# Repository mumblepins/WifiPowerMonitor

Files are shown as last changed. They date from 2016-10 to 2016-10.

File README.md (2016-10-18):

# Particle power monitor

Uses the [Particle](http://particle.io) Photon by default, but probably would work with a Core or one of the other Particle type devices.

Interfaces with a ST STPM34 ADC power-monitoring front-end and is designed for 2 CTs and 2 voltage inputs.  Resistors are sized in general for a 100A → 50mA current transformer, and 120V (US) voltage source.  Unlike the [OpenEnergyMonitor](https://openenergymonitor.org/emon/), we're using a seperate 24-bit ADC, and no voltage transformer. 

###License
#### Hardware
<br />This work is licensed under a <a rel="license" href="http://creativecommons.org/licenses/by-sa/4.0/">Creative Commons Attribution-ShareAlike 4.0 International License</a>.

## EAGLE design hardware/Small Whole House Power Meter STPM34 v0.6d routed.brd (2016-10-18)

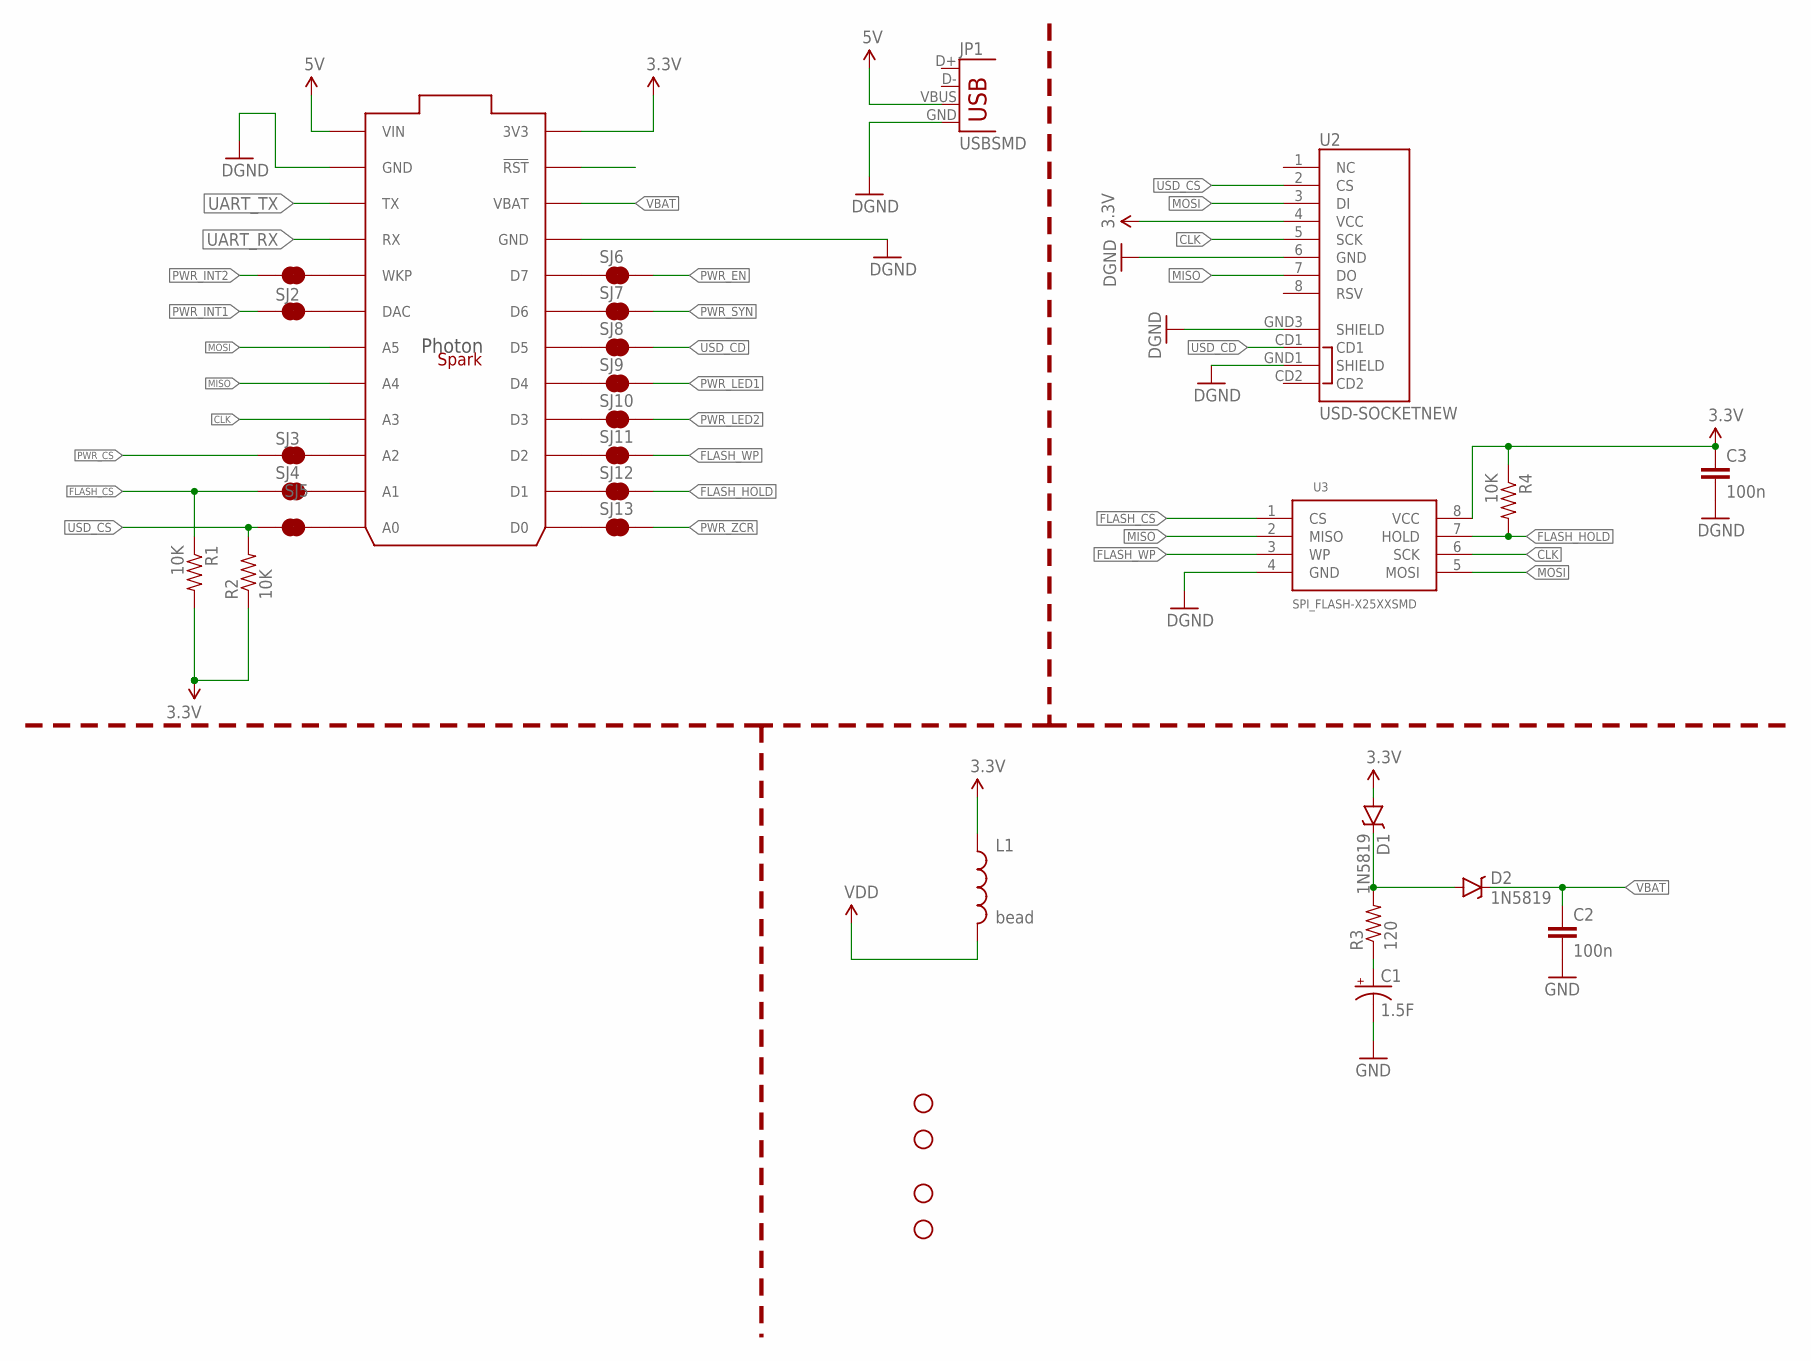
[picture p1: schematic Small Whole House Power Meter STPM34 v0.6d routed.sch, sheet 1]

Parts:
C1: 1.5F; 1.5SUPERCAPHORIZ
C2, C3: 100n; 0603-CAP
D1, D2: 1N5819; SOD-123
JP1: USBSMD; USB-MINIB
L1: bead; 0603
M1: SPARK_LOGO..; SPARK_LOGO
R1, R2, R4: 10K; 0603-RES
R3: 120; 0603-RES
SJ1, SJ2, SJ3, SJ4, SJ5, SJ6, SJ7, SJ8, SJ9, SJ10, SJ11, SJ12, SJ13: JUMPER-PAD-2-NC_BY_TRACE; PAD-JUMPER-2-NC_BY_TRACE_YES_SILK
STANDOFF1, STANDOFF2, STANDOFF3, STANDOFF4: STAND-OFF
U1: PHOTON_SMD_W_PINS
U2: USD-SOCKETNEW; MICRO-SD-SOCKET-PP
U3: SPI_FLASH-X25XXSMD; SO08N/W

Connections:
3.3V: C3.1, D1.A, L1.1, R1.2, R2.1, R4.1, U1.1_24 (3V3), U1.24 (3V3), U1.24* (3V3), U1.24_ (3V3), U2.4 (VCC), U3.8 (VCC)
5V: JP1.VBUS, U1.1 (VIN), U1.1* (VIN), U1.1_ (VIN), U1.1_1 (VIN)
CLK: U1.1_9 (A3), U1.9 (A3), U1.9* (A3), U1.9_ (A3), U2.5 (SCK), U3.6 (SCK); also elsewhere on the board
FLASH_CS: R1.1, SJ4.1, U3.1 (CS)
FLASH_HOLD: R4.2, SJ12.2, U3.7 (HOLD)
FLASH_WP: SJ11.2, U3.3 (WP)
GND: C1.-, C2.2, C3.2, JP1.GND, U1.1_2 (GND), U1.1_21 (GND), U1.2 (GND), U1.2* (GND), U1.2_ (GND), U1.21 (GND), U1.21* (GND), U1.21_ (GND), U2.6 (GND), U2.GND1 (SHIELD), U2.GND3 (SHIELD), U3.4 (GND); also elsewhere on the board
MISO: U1.1_8 (A4), U1.8 (A4), U1.8* (A4), U1.8_ (A4), U2.7 (DO), U3.2 (MISO); also elsewhere on the board
MOSI: U1.1_7 (A5), U1.7 (A5), U1.7* (A5), U1.7_ (A5), U2.3 (DI), U3.5 (MOSI); also elsewhere on the board
unnamed: SJ13.1, U1.1_13 (D0), U1.13 (D0), U1.13* (D0), U1.13_ (D0)
unnamed: U1.1_23 (!RST), U1.23 (!RST), U1.23* (!RST), U1.23_ (!RST)
unnamed: C1.+, R3.1
unnamed: SJ11.1, U1.1_15 (D2), U1.15 (D2), U1.15* (D2), U1.15_ (D2)
unnamed: SJ4.2, U1.1_11 (A1), U1.11 (A1), U1.11* (A1), U1.11_ (A1)
unnamed: SJ3.2, U1.1_10 (A2), U1.10 (A2), U1.10* (A2), U1.10_ (A2)
unnamed: SJ2.2, U1.1_6 (DAC), U1.6 (DAC), U1.6* (DAC), U1.6_ (DAC)
unnamed: SJ1.2, U1.1_5 (WKP), U1.5 (WKP), U1.5* (WKP), U1.5_ (WKP)
unnamed: SJ6.1, U1.1_20 (D7), U1.20 (D7), U1.20* (D7), U1.20_ (D7)
unnamed: SJ7.1, U1.1_19 (D6), U1.19 (D6), U1.19* (D6), U1.19_ (D6)
unnamed: SJ8.1, U1.1_18 (D5), U1.18 (D5), U1.18* (D5), U1.18_ (D5)
unnamed: SJ9.1, U1.1_17 (D4), U1.17 (D4), U1.17* (D4), U1.17_ (D4)
unnamed: SJ12.1, U1.1_14 (D1), U1.14 (D1), U1.14* (D1), U1.14_ (D1)
unnamed: SJ10.1, U1.1_16 (D3), U1.16 (D3), U1.16* (D3), U1.16_ (D3)
unnamed: D1.C, D2.A, R3.2
unnamed: SJ5.2, U1.1_12 (A0), U1.12 (A0), U1.12* (A0), U1.12_ (A0)
PWR_CS: SJ3.1; also elsewhere on the board
PWR_EN: SJ6.2; also elsewhere on the board
PWR_INT1: SJ2.1; also elsewhere on the board
PWR_INT2: SJ1.1; also elsewhere on the board
PWR_LED1: SJ9.2; also elsewhere on the board
PWR_LED2: SJ10.2; also elsewhere on the board
PWR_SYN: SJ7.2; also elsewhere on the board
PWR_ZCR: SJ13.2; also elsewhere on the board
UART_RX: U1.1_4 (RX), U1.4 (RX), U1.4* (RX), U1.4_ (RX)
UART_TX: U1.1_3 (TX), U1.3 (TX), U1.3* (TX), U1.3_ (TX)
USD_CD: SJ8.2, U2.CD1
USD_CS: R2.2, SJ5.1, U2.2 (CS)
VBAT: C2.1, D2.C, U1.1_22 (VBAT), U1.22 (VBAT), U1.22* (VBAT), U1.22_ (VBAT)
VDD: L1.2; also elsewhere on the board

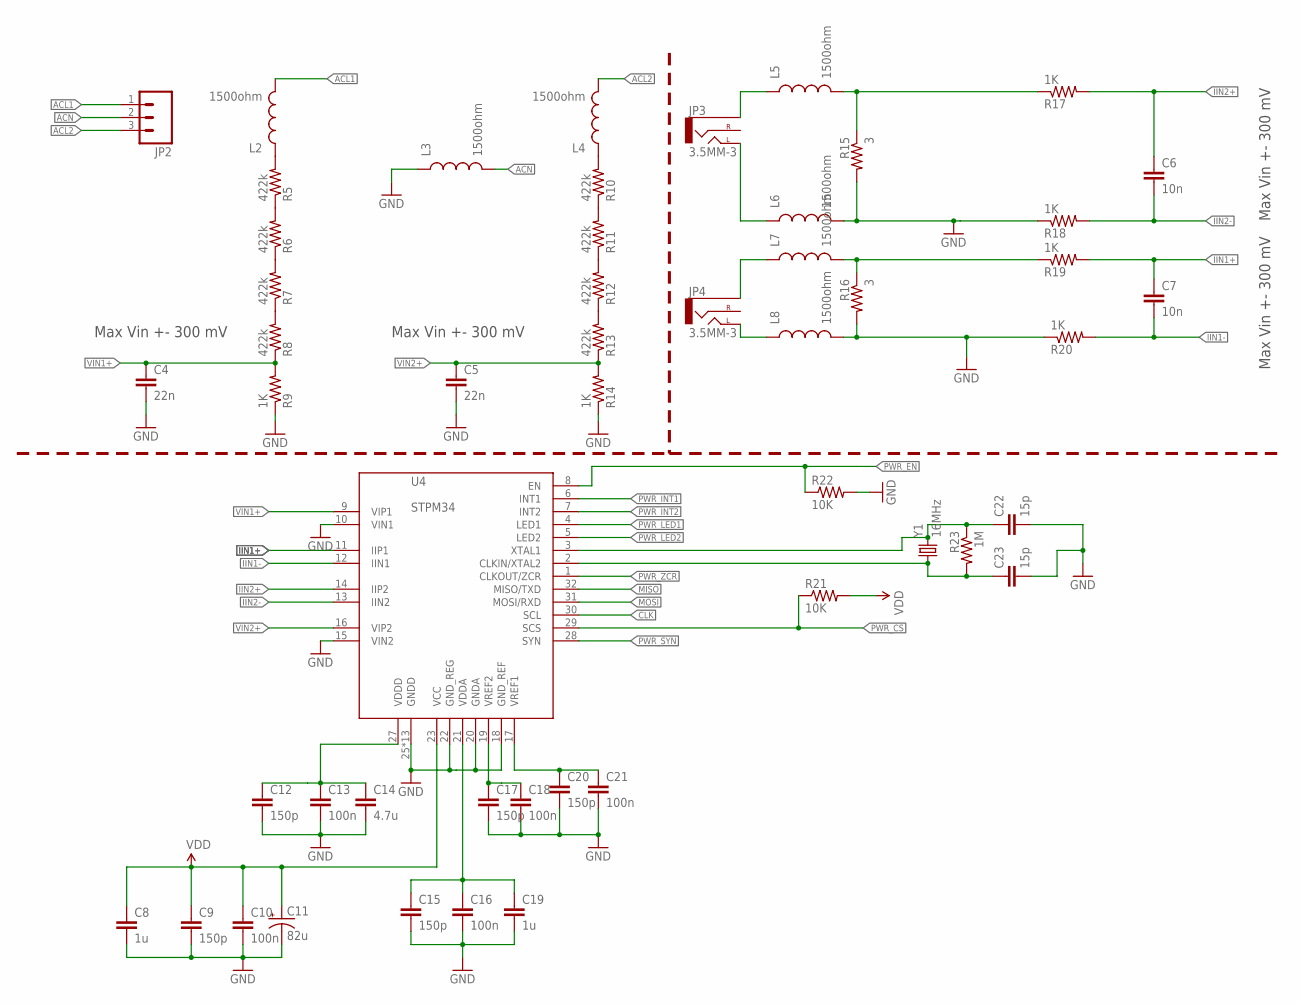
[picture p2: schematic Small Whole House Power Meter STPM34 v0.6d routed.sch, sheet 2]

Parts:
C4, C5: 22n; 0603-CAP
C6, C7: 10n; 0603-CAP
C8, C19: 1u; 0603-CAP
C9, C12, C15, C17, C20: 150p; 0603-CAP
C10, C13, C16, C18, C21: 100n; 0603-CAP
C11: 82u; CPOL-RADIAL-10UF-25V
C14: 4.7u; 0805
C22, C23: 15p; 0603-CAP
JP2: M03-SCREW-5MM; SCREWTERMINAL-5MM-3
JP3, JP4: 3.5MM-3; AUDIO-JACK
L2, L3, L4, L5, L6, L7, L8: 1500ohm; 0603
R5, R6, R7, R8, R10, R11, R12, R13: 422k; 1206
R9, R14, R17, R18, R19, R20: 1K; 0603-RES
R15, R16: 3; 0805
R21, R22: 10K; 0603-RES
R23: 1M; 0603-RES
U4: STPM34; UFQFPN32
Y1: 16MHz; HC49US

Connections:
ACL1: JP2.1, L2.2
ACL2: JP2.3, L4.2
ACN: JP2.2, L3.2
CLK: U4.30 (SCL); also elsewhere on the board
CUR_TRAN1+: L7.2, R16.1, R19.1
CUR_TRAN2+: L5.2, R15.1, R17.1
GND: C4.2, C5.2, C8.2, C9.2, C10.2, C11.2 (-), C12.2, C13.2, C14.2, C15.2, C16.2, C17.2, C18.2, C19.2, C20.2, C21.2, C22.2, C23.2, L3.1, L6.2, L8.2, R9.1, R14.1, R15.2, R16.2, R18.1, R20.1, R22.2, U4.10 (VIN1), U4.15 (VIN2), U4.18 (GND_REF), U4.20 (GNDA), U4.22 (GND_REG), U4.25 (GNDD), U4.26 (GNDD), U4.EXP (GNDD), U4.EXP1 (GNDD), U4.P$1 (GNDD), U4.P$2 (GNDD), U4.P$3 (GNDD), U4.P$4 (GNDD), U4.P$5 (GNDD), U4.P$6 (GNDD), U4.P$7 (GNDD), U4.P$8 (GNDD), U4.P$9 (GNDD); also elsewhere on the board
IIN1+: C7.1, R19.2, U4.11 (IIP1)
IIN1-: C7.2, R20.2, U4.12 (IIN1)
IIN2+: C6.1, R17.2, U4.14 (IIP2)
IIN2-: C6.2, R18.2, U4.13 (IIN2)
MISO: U4.32 (MISO/TXD); also elsewhere on the board
MOSI: U4.31 (MOSI/RXD); also elsewhere on the board
unnamed: L2.1, R5.2
unnamed: L4.1, R10.2
unnamed: C20.1, C21.1, U4.17 (VREF1)
unnamed: C23.1, R23.2, U4.2 (CLKIN/XTAL2), Y1.1
unnamed: C22.1, R23.1, U4.3 (XTAL1), Y1.2
unnamed: C15.1, C16.1, C19.1, U4.21 (VDDA)
unnamed: R7.1, R8.2
unnamed: R6.1, R7.2
unnamed: R5.1, R6.2
unnamed: R12.1, R13.2
unnamed: R11.1, R12.2
unnamed: R10.1, R11.2
unnamed: C17.1, C18.1, U4.19 (VREF2)
unnamed: JP4.TIP (LEFT), L8.1
unnamed: JP3.TIP (LEFT), L6.1
unnamed: JP3.SLEEVE, L5.1
unnamed: JP4.SLEEVE, L7.1
unnamed: C12.1, C13.1, C14.1, U4.27 (VDDD)
PWR_CS: R21.1, U4.29 (SCS); also elsewhere on the board
PWR_EN: R22.1, U4.8 (EN); also elsewhere on the board
PWR_INT1: U4.6 (INT1); also elsewhere on the board
PWR_INT2: U4.7 (INT2); also elsewhere on the board
PWR_LED1: U4.4 (LED1); also elsewhere on the board
PWR_LED2: U4.5 (LED2); also elsewhere on the board
PWR_SYN: U4.28 (SYN); also elsewhere on the board
PWR_ZCR: U4.1 (CLKOUT/ZCR); also elsewhere on the board
VDD: C8.1, C9.1, C10.1, C11.1 (+), R21.2, U4.23 (VCC); also elsewhere on the board
VIN1+: C4.1, R8.1, R9.2, U4.9 (VIP1)
VIN2+: C5.1, R13.1, R14.2, U4.16 (VIP2)

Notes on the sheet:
Max Vin +- 300 mV

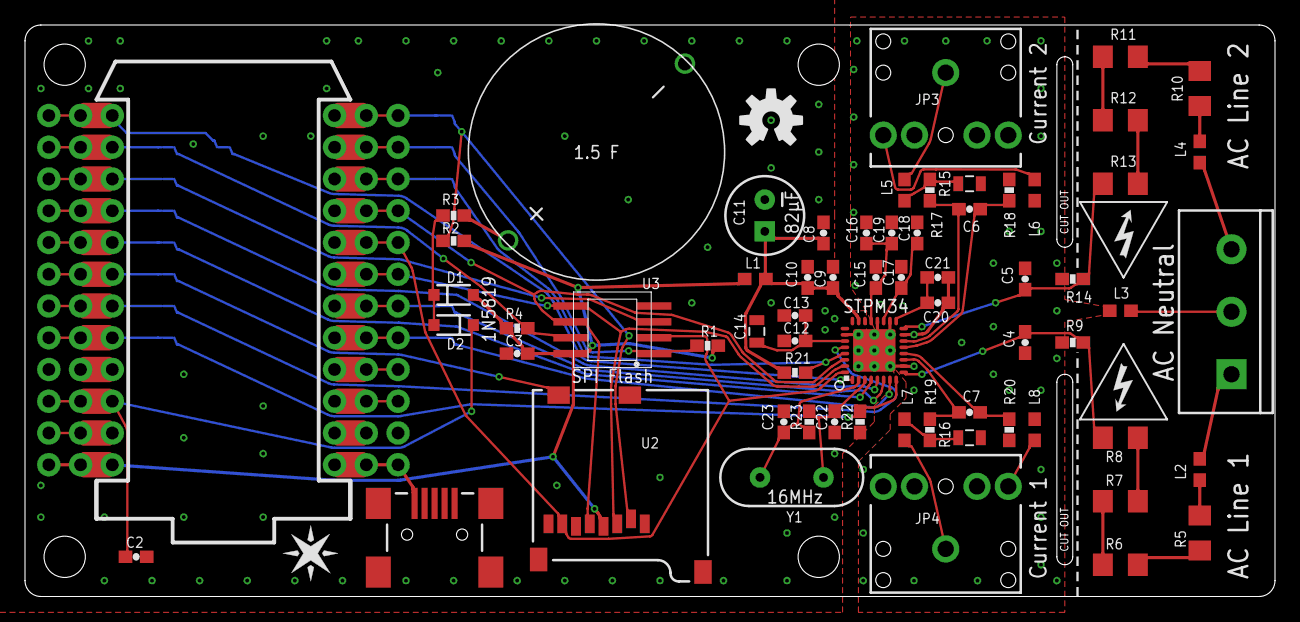
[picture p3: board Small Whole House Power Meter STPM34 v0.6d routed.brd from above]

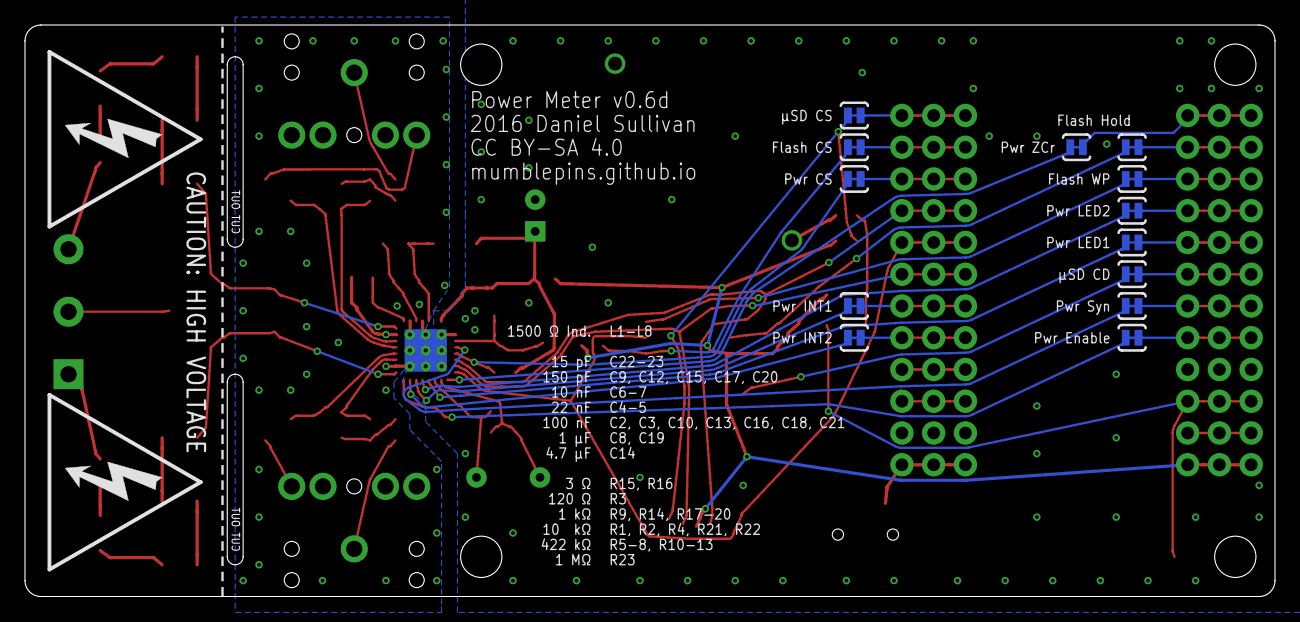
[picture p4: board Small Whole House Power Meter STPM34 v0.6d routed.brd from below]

Board: 2 copper layers, 100.0 x 45.7 mm, 88 parts (15 on the bottom side), 68 nets.

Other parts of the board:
E$1, E$5: HIGH_VOLTAGE
E$2, E$3: HIGH_VOLTAGE_HALF
E$4: OSHW-LOGO-M

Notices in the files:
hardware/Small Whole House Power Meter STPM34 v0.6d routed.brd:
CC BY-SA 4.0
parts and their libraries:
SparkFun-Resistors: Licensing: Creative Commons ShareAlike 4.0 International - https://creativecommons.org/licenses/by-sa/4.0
